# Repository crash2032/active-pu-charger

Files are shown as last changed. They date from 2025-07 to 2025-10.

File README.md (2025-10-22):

# Rechargeable Battery Pack For Active Guitar Pickups 🎸🔋

## Based on https://www.freestompboxes.org/viewtopic.php?t=32759

## 🔥 Overview
This **open-source** project offers a **smart, rechargeable battery pack** designed specifically for **active guitar pickups** such as **EMG, Fishman Fluence, Seymour Duncan,** and similar. The design provides **noise-free** performance, **automatic shutdown** when the cable is disconnected (requires stereo jack), and includes a **charging indicator** for a seamless playing experience.

## 🛠️ What's Included
- **KiCAD source files** for easy customization
- **Pre-generated Gerber files** for instant PCB fabrication
- **Bill of Materials (BOM)** for component procurement

## 🎯 Key Features
- **Designed for active guitar pickups**: low noise, reliable power
- **Automatic shutdown**: saves power when cable is unplugged (requires stereo jack)
- **Charging indication**: integrated LED indicators
- **Compact & lightweight** design
- **Open-source**: full design files for modification and enhancement

## 🚀 Get Started
### Fabricate your own
1. **Download** the `Gerbers.zip`
2. **Order** PCB fabrication from your preferred manufacturer
3. **Gather** components listed in the `PU-BOM.xlsx`
4. **Assemble** according to your needs

### Customize
- **Clone or fork** this repository
- Use **KiCAD** to modify schematics or layout
- **Regenerate Gerbers** for customized PCBs

## 🤝 Contributing
Contributions are **welcome**! Fork the repo, make improvements, and submit **pull requests**.

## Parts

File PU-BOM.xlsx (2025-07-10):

Item # | *Designator | *Qty | Manufacturer | *Mfg Part # | Description / Value | *Package/Footprint | Type | Your Instructions / Notes
1 | U2 | 1 | Texas Instruments | TPS61041DBVR | TPS61041DBVR Switching Voltage Regulators 28-V 250-mA Switch Boost Converter | SOT-23-5 | SMD
2 | U1 | 1 | TPOWER |  | TP4056 Standalone Li-Ion Battery Charger w/ Thermal Regulation; Vreg 4,2V; 1A; 4,5V~6,5V; | SOP-8 | SMD
3 | Rref1 | 1 |  |  | 1.58K Resistor SMD | 0805 (2012 metric) | SMD
4 | R11 | 1 |  |  | 270R Resistor SMD | 0805 (2012 metric) | SMD
5 | R10 | 1 |  |  | 470R Resistor SMD | 0805 (2012 metric) | SMD
6 | R8,R9 | 2 |  |  | 200K Resistor SMD | 0805 (2012 metric) | SMD
7 | R7 | 1 |  |  | 1M43 Resistor SMD | 0805 (2012 metric) | SMD
8 | R4,R5,R6 | 3 |  |  | 47K Resistor SMD | 0805 (2012 metric) | SMD
9 | R3 | 1 |  |  | 1M Resistor SMD | 0805 (2012 metric) | SMD
10 | R2 | 1 |  |  | 10R Resistor SMD | 0805 (2012 metric) | SMD
11 | R1 | 1 |  |  | 20K Resistor SMD | 0805 (2012 metric) | SMD
12 | Q6 | 1 | Comchip Technology |  | BC847 Bipolar Transistors - BJT 6V, 10uA | SOT-23-3 | SMD
13 | Q2,Q7 | 2 | Infineon Technologies |  | BC857 Bipolar Transistors - BJT PNP Silicon AF TRANSISTOR | SOT-23-3 | SMD
14 | Q1 | 1 | Infineon Technologies | IRLML6402TRPBF | IRLML6402 | SOT-23-3 | SMD
15 | L1,L2,L3 | 3 |  |  | 10µH | 0805 (2012 metric) | SMD
16 | D4 | 1 |  |  | Single Colour LEDs RED 637nm 90mcd DIFF | 0805 (2012 metric) | SMD
17 | D3 | 1 |  |  | Single Colour LEDs Pure Green, 525nm 3.5V, 45mcd | 0805 (2012 metric) | SMD
18 | D1,D2 | 2 |  |  | Zener Diodes 500mW, 2%, Small Signal Zener Diode | 0805 (2012 metric) | SMD
19 | C10 | 1 |  |  | Multilayer Ceramic Capacitors MLCC - SMD/SMT MLCC,10 pF, +/- 0.25pF, 0402, 50V, C0H/CH, T&R | 0402 (1005 metric) | SMD
20 | C7 | 1 |  |  | Tantalum Capacitors - Solid SMD 47 uF 10volts 10% | 3528-12 Metric | SMD
21 | C5 | 1 |  |  | Tantalum Capacitors - Solid SMD 100uF 10volts 10% D case Molded | 7343-15 Metric | SMD
22 | C2,C3,C6,C13 | 4 |  |  | Tantalum Capacitors - Solid SMD 10V 10uF 1206 10% ESR=4Ohms | 3216-10 Metric | SMD
23 | C1,C4,C8,C9,C11,C12,C14 | 7 |  |  | Multilayer Ceramic Capacitors MLCC - SMD/SMT 100volt 100nF 10% | 0805 (2012 metric) | SMD

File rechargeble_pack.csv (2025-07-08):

# | Reference | Datasheet | Value | Footprint | Qty | DNP | Exclude from BOM | Exclude from Board
1 | U2 | http://www.ti.com/lit/ds/symlink/tps61040.pdf | TPS61041 | Package_TO_SOT_SMD:SOT-23-5 | 1
2 | U1 | https://www.lcsc.com/datasheet/lcsc_datasheet_2410121619_TOPPOWER-Nanjing-Extension-Microelectronics-TP4056-42-ESOP8_C16581.pdf | TP4056 | Package_SO:SOIC-8-1EP_3.9x4.9mm_P1.27mm_EP2.41x3.3mm_ThermalVias | 1
3 | Rref1 | ~ | 1.58K | Resistor_SMD:R_0805_2012Metric | 1
4 | R11 | ~ | 270R | Resistor_SMD:R_0805_2012Metric | 1
5 | R10 | ~ | 470R | Resistor_SMD:R_0805_2012Metric | 1
6 | R8,R9 | ~ | 200k | Resistor_SMD:R_0805_2012Metric | 2
7 | R7 | ~ | 1M43 | Resistor_SMD:R_0805_2012Metric | 1
8 | R4,R5,R6 | ~ | 47k | Resistor_SMD:R_0805_2012Metric | 3
9 | R3 | ~ | 1M | Resistor_SMD:R_0805_2012Metric | 1
10 | R2 | ~ | 10R | Resistor_SMD:R_0805_2012Metric | 1
11 | R1 | ~ | 20k | Resistor_SMD:R_0805_2012Metric | 1
12 | Q6 | http://www.infineon.com/dgdl/Infineon-BC847SERIES_BC848SERIES_BC849SERIES_BC850SERIES-DS-v01_01-en.pdf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 | BC847 | Package_TO_SOT_SMD:SOT-23 | 1
13 | Q2,Q7 | https://www.onsemi.com/pub/Collateral/BC860-D.pdf | BC857 | Package_TO_SOT_SMD:SOT-23 | 2
14 | Q1 | https://ngspice.sourceforge.io/docs/ngspice-html-manual/manual.xhtml#cha_MOSFETs | SIA453 | Package_TO_SOT_SMD:SOT-23 | 1
15 | L1,L2,L3 | ~ | 10µH | Inductor_SMD:L_0805_2012Metric | 3
16 | J3 | ~ | DC IN | Connector_Wire:SolderWire-0.5sqmm_1x02_P4.8mm_D0.9mm_OD2.3mm | 1
17 | J2 | ~ | LiPo | Connector_Wire:SolderWire-0.5sqmm_1x02_P4.8mm_D0.9mm_OD2.3mm | 1
18 | J1 | ~ | Out | Connector_Wire:SolderWire-0.5sqmm_1x03_P4.8mm_D0.9mm_OD2.3mm | 1
19 | D4 | ~ | RED | LED_SMD:LED_0805_2012Metric | 1
20 | D3 | ~ | GREEN | LED_SMD:LED_0805_2012Metric | 1
21 | D1,D2 | ~ | D | Diode_SMD:D_0805_2012Metric | 2
22 | C10 | ~ | 10pF | Capacitor_SMD:C_0402_1005Metric | 1
23 | C7 | ~ | 47uF | Capacitor_Tantalum_SMD:CP_EIA-3528-12_Kemet-T | 1
24 | C5 | ~ | 100uF | Capacitor_Tantalum_SMD:CP_EIA-7343-15_Kemet-W | 1
25 | C2,C3,C6,C13 | ~ | 10uF | Capacitor_Tantalum_SMD:CP_EIA-3216-10_Kemet-I | 4
26 | C1,C4,C8,C9,C11,C12,C14 | ~ | 100nF | Capacitor_SMD:C_0805_2012Metric | 7

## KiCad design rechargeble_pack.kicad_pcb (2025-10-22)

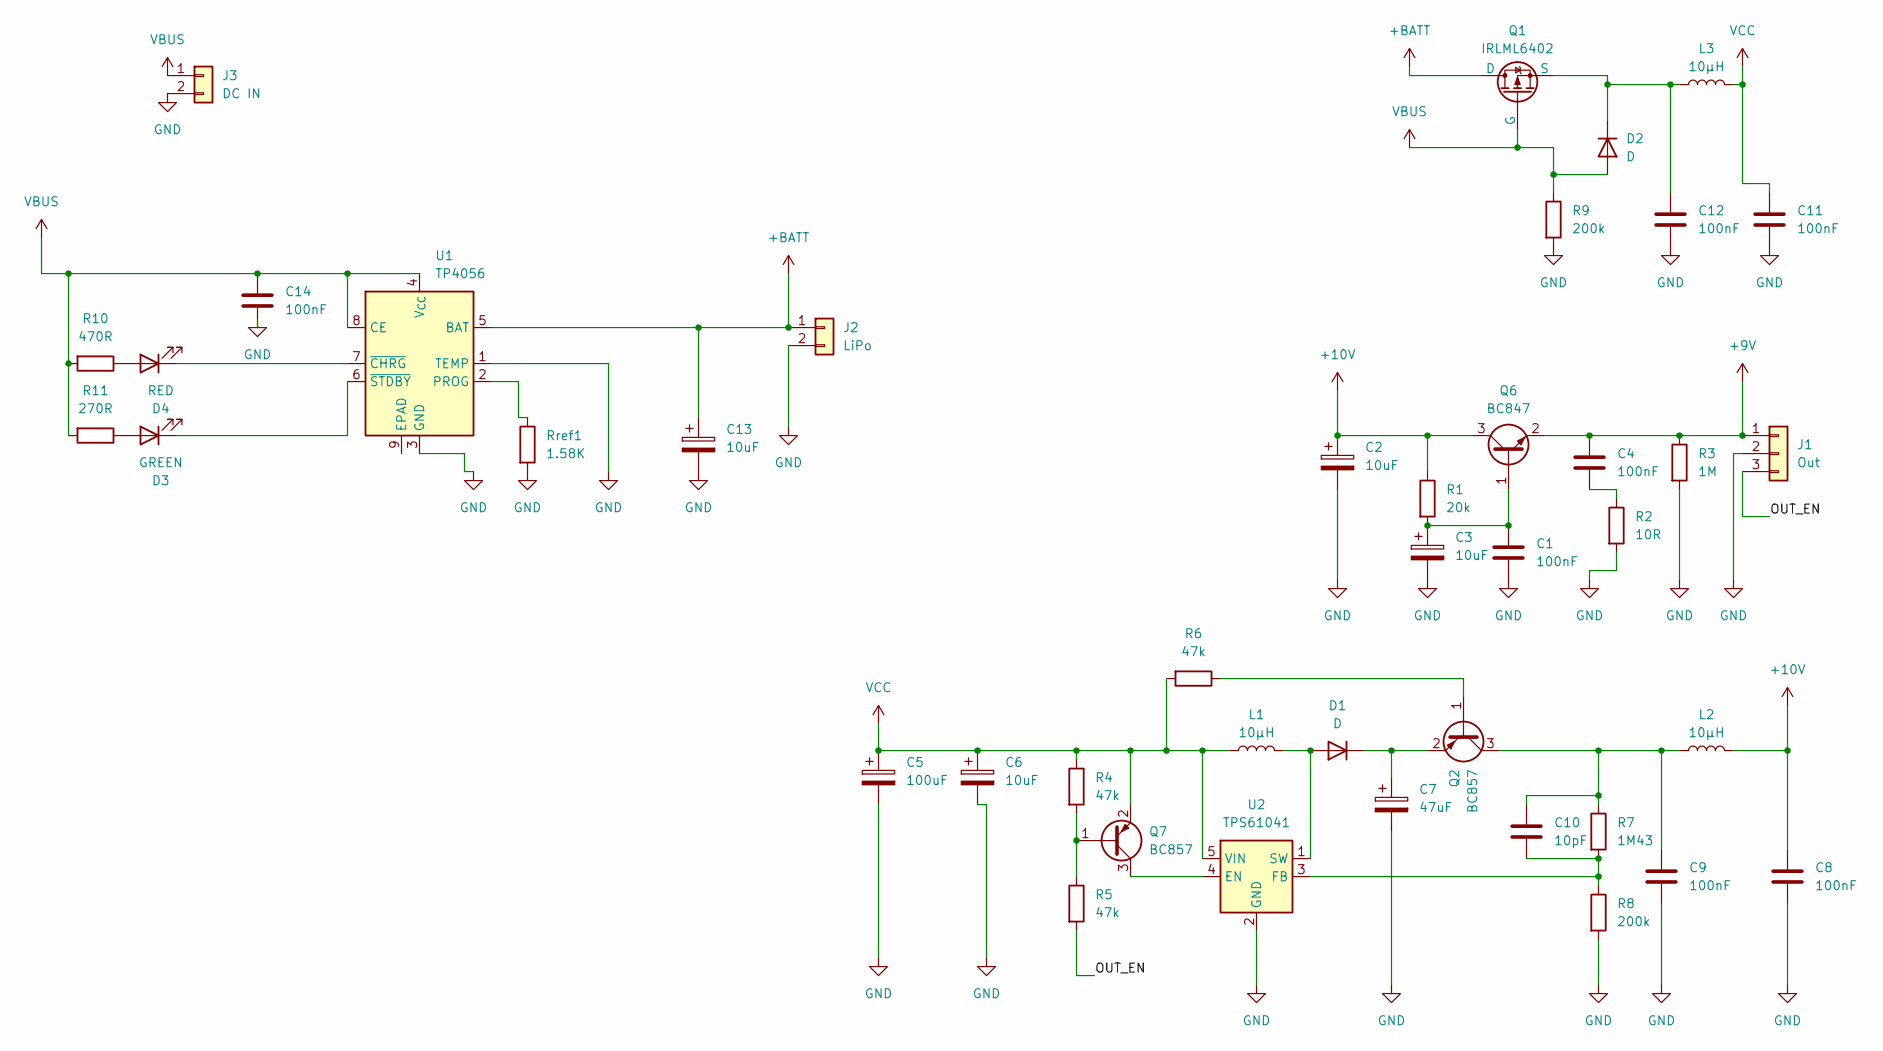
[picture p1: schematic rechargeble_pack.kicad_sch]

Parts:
C1, C4, C8, C9, C11, C12, C14: 100nF; C_0805_2012Metric
C2, C3, C6, C13: 10uF; CP_EIA-3216-10_Kemet-I
C5: 100uF; CP_EIA-7343-15_Kemet-W
C7: 47uF; CP_EIA-3528-12_Kemet-T
C10: 10pF; C_0402_1005Metric
D1, D2: D; D_0805_2012Metric
D3: GREEN; LED_0805_2012Metric
D4: RED; LED_0805_2012Metric
J1: Out; SolderWire-0.5sqmm_1x03_P4.8mm_D0.9mm_OD2.3mm
J2: LiPo; SolderWire-0.5sqmm_1x02_P4.8mm_D0.9mm_OD2.3mm
J3: DC IN; SolderWire-0.5sqmm_1x02_P4.8mm_D0.9mm_OD2.3mm
L1, L2, L3: 10µH; L_0805_2012Metric
Q1: IRLML6402; SOT-23
Q2, Q7: BC857; SOT-23
Q6: BC847; SOT-23
R1: 20k; R_0805_2012Metric
R2: 10R; R_0805_2012Metric
R3: 1M; R_0805_2012Metric
R4, R5, R6: 47k; R_0805_2012Metric
R7: 1M43; R_0805_2012Metric
R8, R9: 200k; R_0805_2012Metric
R10: 470R; R_0805_2012Metric
R11: 270R; R_0805_2012Metric
Rref1: 1.58K; R_0805_2012Metric
U1: TP4056; SOIC-8-1EP_3.9x4.9mm_P1.27mm_EP2.41x3.3mm_ThermalVias
U2: TPS61041; SOT-23-5

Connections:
+9V: C4.1, J1.1, Q6.2 (E), R3.1
+10V: C2.1, C8.1, L2.2, Q6.3 (C), R1.1
+BATT: C13.1, J2.1, Q1.1 (D), U1.5 (BAT)
/OUT_EN: J1.3, R5.2
GND: C1.2, C2.2, C3.2, C5.2, C6.2, C7.2, C8.2, C9.2, C11.2, C12.2, C13.2, C14.2, J1.2, J2.2, J3.2, R2.2, R3.2, R8.2, R9.2, Rref1.2, U1.1 (TEMP), U1.3 (GND), U2.2 (GND)
unnamed: C4.2, R2.1
unnamed: D1.2 (A), L1.2, U2.1 (SW)
unnamed: C7.1, D1.1 (K), Q2.2 (E)
unnamed: C12.1, D2.1 (K), L3.1, Q1.3 (S)
unnamed: D3.2 (A), R11.1
unnamed: D3.1 (K), U1.6 (~STDBY)
unnamed: D4.2 (A), R10.1
unnamed: D4.1 (K), U1.7 (~CHRG)
unnamed: Q2.1 (B), R6.1
unnamed: C9.1, C10.1, L2.1, Q2.3 (C), R7.1
unnamed: C1.1, C3.1, Q6.1 (B), R1.2
unnamed: Q7.1 (B), R4.2, R5.1
unnamed: Q7.3 (C), U2.4 (EN)
unnamed: Rref1.1, U1.2 (PROG)
unnamed: C10.2, R7.2, R8.1, U2.3 (FB)
VBUS: C14.1, D2.2 (A), J3.1, Q1.2 (G), R9.1, R10.2, R11.2, U1.4 (V_{CC}), U1.8 (CE)
VCC: C5.1, C6.1, C11.1, L1.1, L3.2, Q7.2 (E), R4.1, R6.2, U2.5 (VIN)

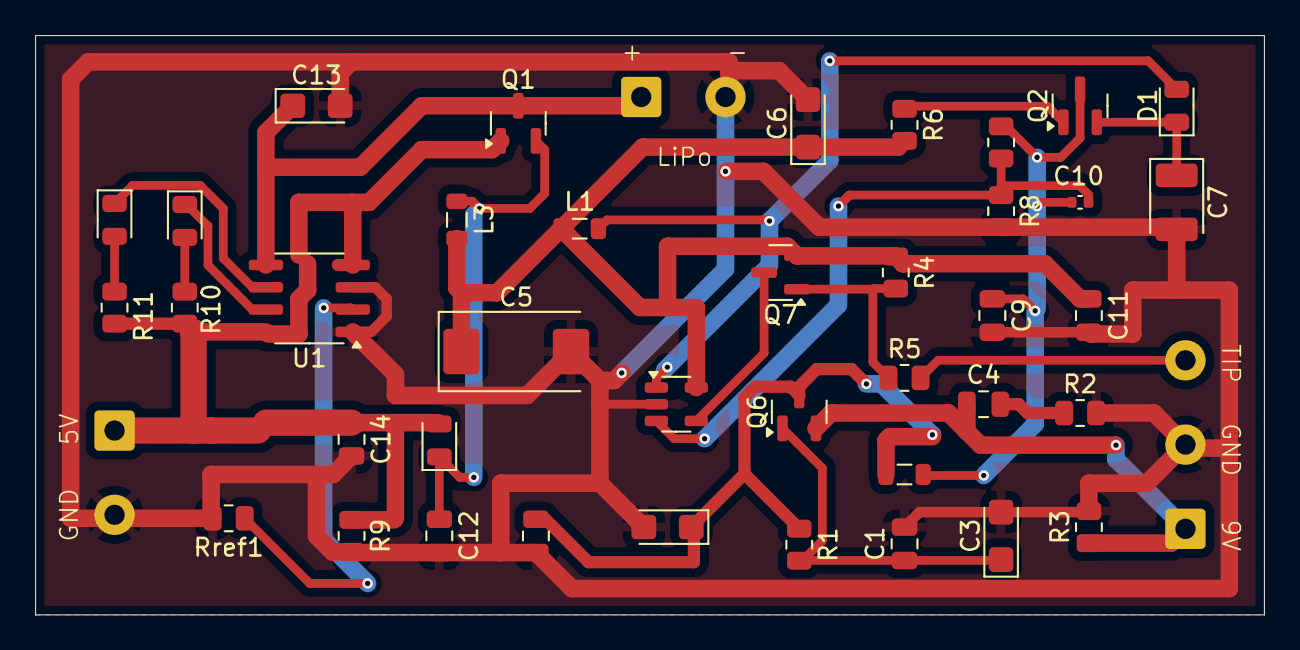
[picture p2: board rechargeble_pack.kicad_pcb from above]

Board: 2 copper layers, 70.0 x 33.0 mm, 42 parts (0 on the bottom side), 22 nets.

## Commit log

2025-07-04 added kicad files
    [rechargeble_pack.kicad_pcb, rechargeble_pack.kicad_sch]
2025-07-07 Schematics fix
    Schematics values fix
    [rechargeble_pack.kicad_sch]
2025-07-08 gerber-ready
    gerber+bom
    [rechargeble_pack-B_Cu.gbr, rechargeble_pack-B_Mask.gbr, rechargeble_pack-B_Paste.gbr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]
2025-07-09 need fix
    [rechargeble_pack-B_Cu.gbr, rechargeble_pack-B_Mask.gbr, rechargeble_pack-B_Paste.gbr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]
2025-07-10 fix mosfet
    [PU-BOM.xlsx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]
2025-10-22 gnd polygon
    [rechargeble_pack-B_Cu.gbr, rechargeble_pack-B_Mask.gbr, rechargeble_pack-B_Paste.gbr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]
2026-10-23 v3 redesign: 31x19 mm one-sided board, regulated 9.0 V, single LED
    - Charger TP4057 (500 mA), power-path removed, MLCC instead of tantalum
    - Boost TPS61041 at 11.5 V with output disconnect (Q2), EN pull-down fix
    - Output chain: RC -> capacitance multiplier -> TPS7A4901 ultra-low-noise LDO, 9.02 V
    - Single red/green LED: charging / charged / blinking low-battery (TLV3012)
    - USB-C input TVS, project symbol library, JLC basic parts where possible
    - New layout 31x19 mm, 2 layers, all SMD on top, ABYSS logo on bottom silk
    - production/: gerbers, BOM+CPL for JLCPCB and PCBWay
    - README rewritten, .gitignore added, v1 gerbers/BOM/CPL, KiCad backups and caches removed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
